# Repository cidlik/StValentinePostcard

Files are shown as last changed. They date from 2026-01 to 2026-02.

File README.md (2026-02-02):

# Идея

Сделать валентинку в виде печатной платы с микроконтроллером и светодиодами. Должна работать от
часовой батарейки. Основные пункты:

* должна быть дешевой;
* должно быть минимум компонентов (см. предыдущий пункт);
* должна быть низкопотребляющей;
* все компоненты, кроме светодиодов и кнопки, должны быть на обратной стороне платы.

Эскиз на рисунке ниже:

<figure style="text-align: center">
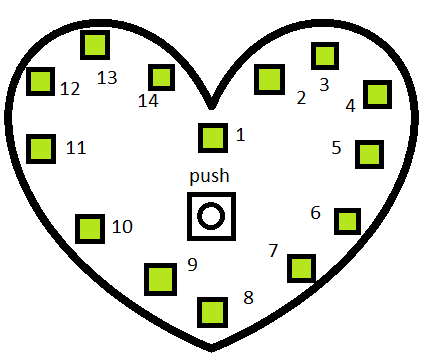
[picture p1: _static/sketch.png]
sketch
	
	<figcaption style="text-align: center">Эскиз устройства</figcaption>
</figure>

# Выбор светодиодов

Основные варианты:

* Обычные светодиоды, например, [TO-1608BC-MRE](https://www.chipdip.ru/product/to-1608bc-mre-svetodiod-krasnyy-smd-1608-112mkd-oasistek-9000414317):

    * (+) дешево
    * (+) энергоэффективно
    * (-) нужно много ног для управления
    * (-) сердито
    * Параметры:

        * Прямой ток 25 мА;
        * Прямое напряжение 2 В.

* Адресный, например, [SK(C)6812-RGBW-BW](https://www.chipdip.ru/product/sk-c-6812-rgbw-bw-neopixel-svetodiod-shenzhen-shiningled-9000373823):

    * (+) красиво, много режимов
    * (+) всего 2 провода для управления
    * (-) скорее всего будет больше жрать, хотя как запрограммировать
    * (-) борьба с наводками???
    * (-) дороже
    * Параметры:

        * Напряжение питания 3.7-5.5 В
        * Прямой ток 20-30 мА на один цвет.

# Оценка потребления

Выбираются 14 светодиодов TO-1608BC-MRE. Ток ограничивается до 15 мА через резистор. Режимы:

1. Один светодиод в единицу времени;
2. Все светодиоды разом (худший случай).

Для первого режима потребление по светодиодам 15 мА. Для второго - 15 * 14 = 210 мА.

Пусть будет _какая-то_ батарейка на 100 мАч (см. [таблицу](https://mosclock.ru/clock/o-garantii/zamena-batareek/tablitsa-sravneniya-chasovykh-batareek/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)). Тогда 

1. 100 / 15 ~= 6 ч на одни только светодиоды;
2. 100 / 210 ~= 0.5 ч на одни только светодиоды.

# Выбор микроконтроллера

Судя по всему, это будет STM32L0. Варианты:

1. [STM32L011F3P6](https://www.chipdip.ru/product/stm32l011f3p6-st-microelectronics-8003145100)
2. [STM32L010F4P6](https://www.chipdip.ru/product/stm32l010f4p6-mikrokontroller-arm-st-microelectronics-9001089803)

Почему STM:

* знаю, что там точно есть режимы с супер низким потреблением;
* знакомая платформа;
* не нужно будет докупать программатор, т.к. он есть.

Вариант 1:

* Корпус: TSSOP-20
* GPIO: 11-15 (зависит от того, что смогу сконфигурировать)
* Напряжение питания от 1.65 до 3.6 В.
* Тактирование от внутренней RC-цепочки.

Вариант 2 не рассматривается, т.к. 1-й вариант более чем устраивает.

# Что говорит ИИ?

* [Ответ 1](https://share.google/aimode/JZRhZsYDs94hqZSMV).
* [Ответ 2](https://share.google/aimode/ylKgjJaCaAhDsedJH).

# Выбор батарейки

Судя по всему, подходит [CR2032](https://www.dart.ru/cataloguenew/others/accumulator/html/cr2032.shtml).
Характеристики:

* выходное напряжение 3 В;
* выходной ток  0.4 мА;
* мощность 210 мА/ч.

# Блок-схема устройства

<figure style="text-align: center">
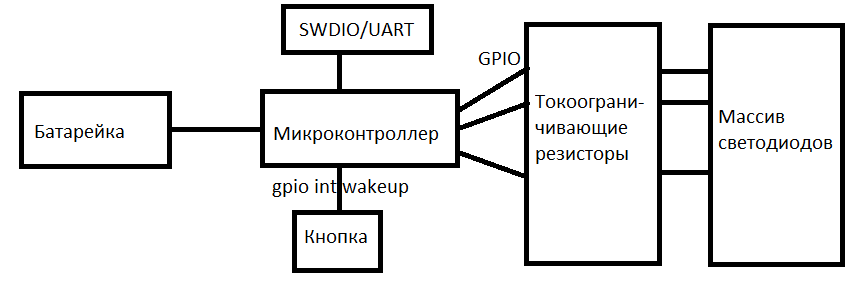
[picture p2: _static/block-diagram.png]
diagram
	
	<figcaption style="text-align: center">Блок-схема устройства</figcaption>
</figure>

# Попытка рассчитать буферный конденсатор

Потребляемая мощность:

$$ P = P_{mc} + P_d $$

где $P_{mc}$ - мощность, потребляемая МК, $P_d$ - мощность, рассеиваемая при зажигании одного
светодиода.

Требуется определить количество энергии, которое будет потреблено за 1 секунду. Оцениваем мощности:

* $ P_d = I^2 \cdot R = 0.015^2 \cdot 120 = 0.027 $ Вт;
* $ P_{mc} = 3 \cdot 0.0005 = 0.0015 $ Вт (грубая оценка, судя по всему не должно превышать этого значения, см.
"Table 22. Current consumption in Run mode, code with data processing running from Flash" для MSI
clock).

Тогда

$$ E = (0.027 + 0.0015) \cdot 1 = 0.0285\ Дж $$

Энергия конденсатора определяется выражением:

$$ E_c = {CU^2 \over 2} $$

Определяем разницу энергий - до включения светодиода и после выключения. Допустим, что напряжение
$U_{low}$ может упасть до 2 В. Эта разница - та энергия, которая уходит на микроконтроллер и на
горение светодиода. Тогда ёмкость:

$$ C = {2E \over U_0^2 - U_{low}^2} = {2 \cdot 0.0285 \over 3^2 - 2^2} = 0.0114\ Ф = 11400\ мкФ $$

Это при условии, что светодиод будет постоянно гореть, а микроконтроллер не будет переводиться в
низкопотребляющие режимы.

Пусть светодиод будет гореть 5% от всего времени, тогда $P_d = 0.027 \cdot 0.05 = 0.00135\ Вт$.
Тогда ёмкость:

$$ C = {2 \cdot (0.0015 + 0.00135) \over 3^2 - 2^2} = 1140\ мкФ$$

# Схема электрическая принципиальная

<figure style="text-align: center">
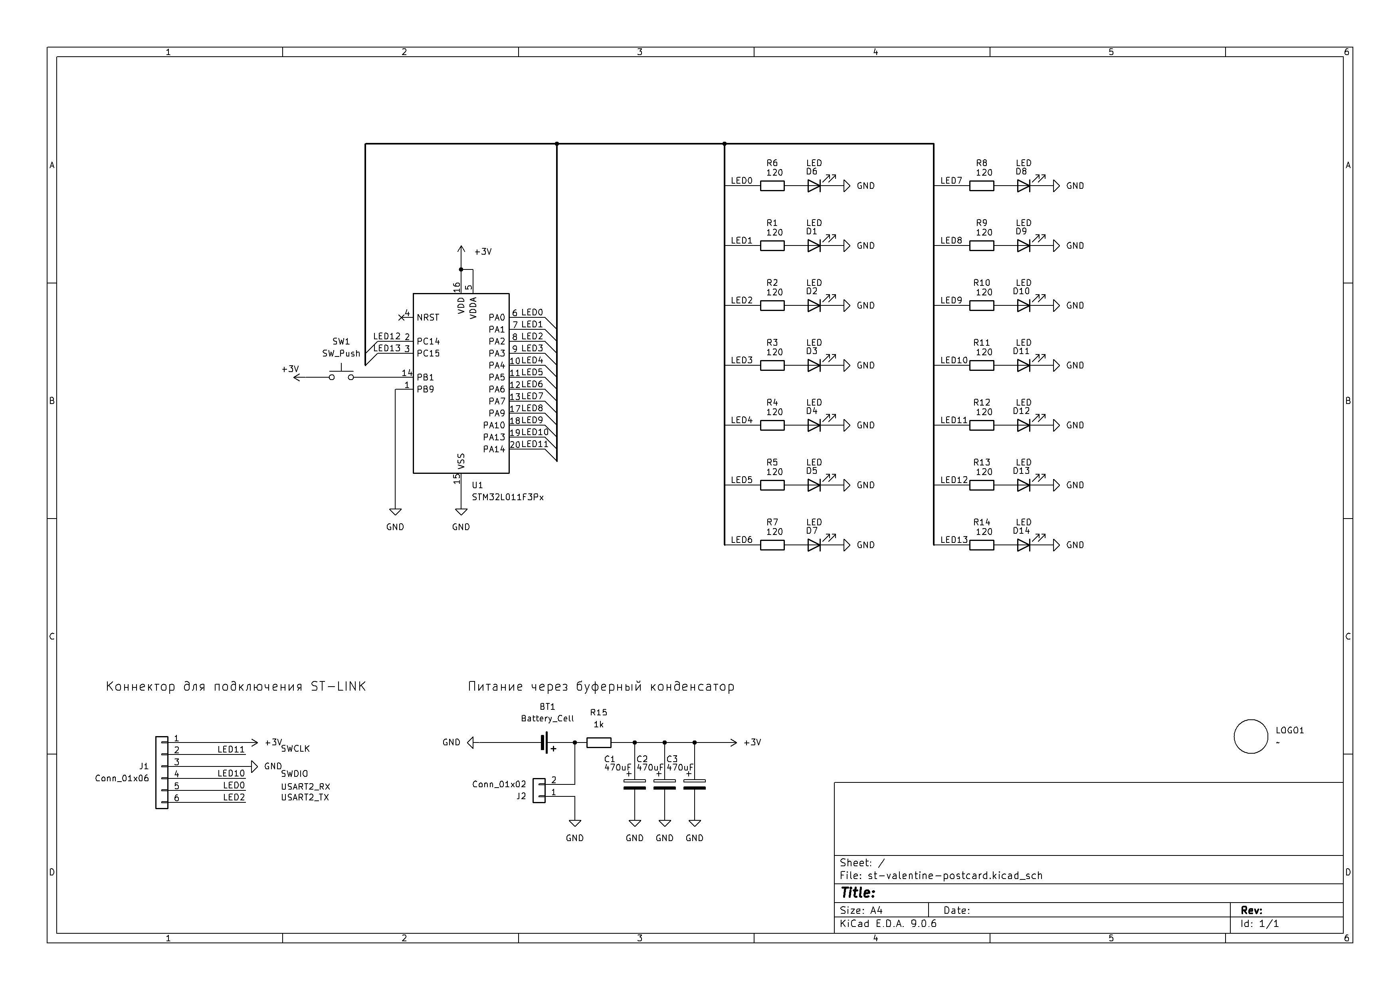
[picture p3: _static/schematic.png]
	
	<figcaption style="text-align: center">Схема электрическая принципиальная</figcaption>
</figure>

# Алгоритм сборки

* Пайка резисторов для светодиодов на нижней стороне платы: флюс, паста, установить резисторы,
  прогреть феном. После операции проверить мультиметром пайку (у каждого резистора есть переходное
  отверстие, использовать его и КП микроконтроллера).
  **Внимание!** R12 и R11 не запаивать!
* Пайка светодиодов на верхней стороне платы: флюс, паста, установить светодиоды, прогреть феном.
  После операции проверить мультиметром пайку (у каждого светодиода есть переходное отверстие,
  использовать его и землю).
* Пайка микроконтроллера: флюс, запаять паяльником краевые выводы. Затем движениями от МК до конца
  площадки нанести припой. После пайки проверить все линии. Проверить, нет ли КЗ по всем линиям.
* Запаять R15.
* Пайка кнопки. Кнопка размещается с верхней стороны. После установки в посадочное место обрезать
  выводы с другой стороны и запаять.
* Прошить МК прошивкой с флагом DEBUG, убедиться, что все ок.
* Прошить МК прошивкой без флага DEBUG.
* Запаять R12 и R11.
* Пайка конденсаторов (вывод с полосой - gnd). ~~Предположительно хватит 2-х конденсаторов~~
  Поставил все 3. Конденсаторы - с нижней стороны. После установки в посадочное   место обрезать
  выводы с другой стороны и запаять.
* Отчистить плату.
* Запаять отсек для батарейки и включить устройство.
* Зашкурить

# Итоговое потребление

* STATE_START: 380 мА (ничего не мигает)
* STATE_RUNNING_LED: 850 мА
* STATE_SYMMETRY_RUNNING_LED: 880 мА

Просадок напряжения питания осциллографом не увидел.

# Что можно улучшить?

## Конструктивно

* Вывести площадку с NRST, чтобы можно было не бояться закирпичить устройство.
* Добавить запаиваемую перемычку после R15, чтобы можно было более удобно измерять силу тока.
* Не забыть шелкографию при производстве плат))0))
* Выбрать какие-то другие светодиоды. Паять эти - сущий ад.

  * Возможно имеет смысл поставить низкопотребляющие светодиоды.

* Сделать площадки светодиодов и резисторов побольше чуть-чуть.
* Исправить посадочное место J1 - сейчас шаг маленький, не могу поставить стандартный PLS.
* Конденсатор после кнопки для фильтрации дребезга.
* Поставить запаиваемые перемычки на линиях LED10 и LED11, чтобы можно было паять сразу все резисторы. Тогда проблем с прошивкой быть не должно.

## Программно

* Улучшить реализацию фильтра дребезга.
* Добавить больше режимов.
* Поддержать Stop и Standby режимы.
* Более тонко понастраивать потребление через задержки.
* Использовать LSI вместо HSI16.

# Итоги

* Устройство заработало.

<figure style="text-align: center">
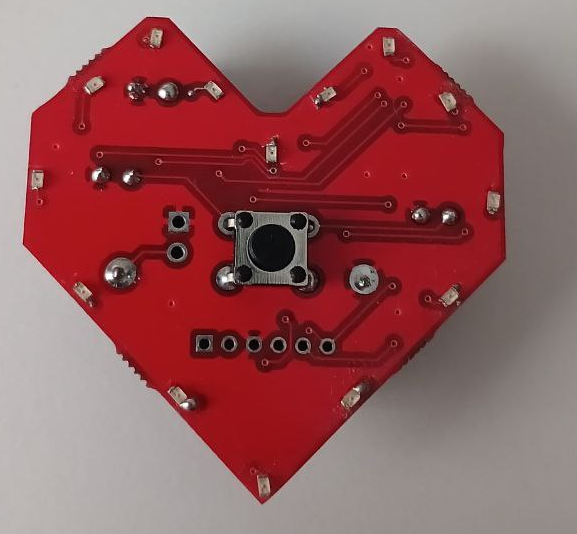
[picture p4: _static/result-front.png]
	
	<figcaption style="text-align: center">Результат. Передняя сторона</figcaption>
</figure>

<figure style="text-align: center">
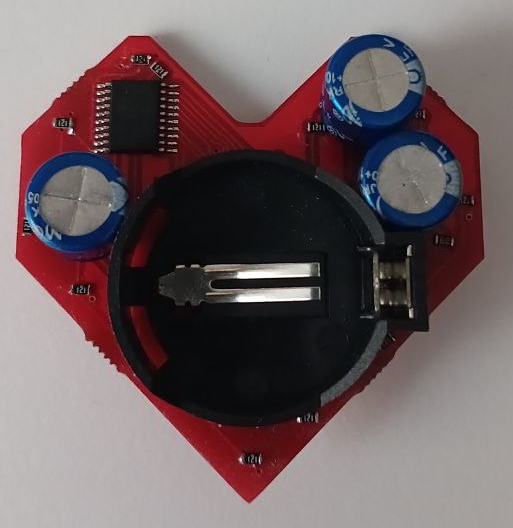
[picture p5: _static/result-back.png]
	
	<figcaption style="text-align: center">Результат. Задняя сторона</figcaption>
</figure>

<figure style="text-align: center">
	sketch
	<figcaption style="text-align: center">Результат в действии</figcaption>
</figure>

* Дешевым проект не назову - платы дорого вышли. Но делал срочный заказ, чтобы успеть к сроку, так
  что пойдет.

* Требование по низкому потреблению выдержано, можно улучшить.

# Для справки

* Светодиоды с низким током потребления:

    * [led smd 1ma](https://www.chipdip.ru/search?searchtext=led+smd+1ma)
    * [VLMA3100-GS08](https://www.chipdip.ru/product/vlma3100-gs08-led-yellow-smd-plcc-2-2-ma-2.2-v-594-vishay-8733971327)

# Полезные ссылки

* [Basics of power supply design for MCU](https://wiki.st.com/stm32mcu/wiki/Basics_of_power_supply_design_for_MCU)
* [Краткое руководство KiCad](https://docs.kicad.org/5.1/ru/getting_started_in_kicad/getting_started_in_kicad.html)
* [Ultra Low Power LED Flasher using the Padauk PFS154](https://cpldcpu.com/2021/02/07/ultra-low-power-led-flasher/)
* [Про буферные конденсаторы](https://habr.com/ru/articles/671232/)

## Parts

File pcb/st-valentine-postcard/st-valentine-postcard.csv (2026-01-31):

Reference | Qty | Value | DNP | Exclude from BOM | Exclude from Board | Footprint | Datasheet
BT1 | 1 | Battery_Cell |  |  |  | Battery:BatteryHolder_KLS5_CR2032_01 | https://www.chipdip.ru/product/kls5-cr2032-01-bh-642-ch224-2032-batareynyy-otsek-na-41183
C1,C2,C3 | 3 | 470uF |  |  |  | Capacitor_THT:C_Radial_D6.3mm_H7.0mm_P2.50mm | https://www.chipdip.ru/product/ecap-k50-35-mini-470mkf-6.3v-8x7mm-jb-capacitors-9000261777
D1,D2,D3,D4,D5,D6,D7,D8,D9,D10,D11,D12,D13,D14 | 14 | LED |  |  |  | Diode_SMD:D_0201_0603Metric | https://www.chipdip.ru/product/ltst-c190kskt-lite-on-electronics-8008844944
J1 | 1 | Conn_01x06 |  |  |  | Connector_PinHeader_2.00mm:PinHeader_1x06_P2.00mm_Vertical | ~
J2 | 1 | Conn_01x02 |  |  |  | Connector_PinHeader_2.54mm:PinHeader_1x02_P2.54mm_Vertical | ~
LOGO1 | 1 | ~ |  |  |  | Symbol:cdk_logo_6x6mm
R1,R2,R3,R4,R5,R6,R7,R8,R9,R10,R11,R12,R13,R14 | 14 | 120 |  |  |  | Resistor_SMD:R_0201_0603Metric_1.6x0.8 | https://www.chipdip.ru/product/0.1vt-0603-120-om-1-rc0603fr-07120rl-chip-rezistor-yageo-9000103458
R15 | 1 | 1k |  |  |  | Resistor_SMD:R_0201_0603Metric_1.6x0.8 | https://www.chipdip.ru/product/0.1vt-0603-1-kom-rc0603fr-071kl-chip-rezistor-smd-yageo-9000176519
SW1 | 1 | SW_Push |  |  |  | Button_Switch_THT:SW_PUSH_6mm_H4.3mm | ~
U1 | 1 | STM32L011F3Px |  |  |  | Package_SO:TSSOP-20_4.4x6.5mm_P0.65mm | https://www.st.com/resource/en/datasheet/stm32l011f3.pdf

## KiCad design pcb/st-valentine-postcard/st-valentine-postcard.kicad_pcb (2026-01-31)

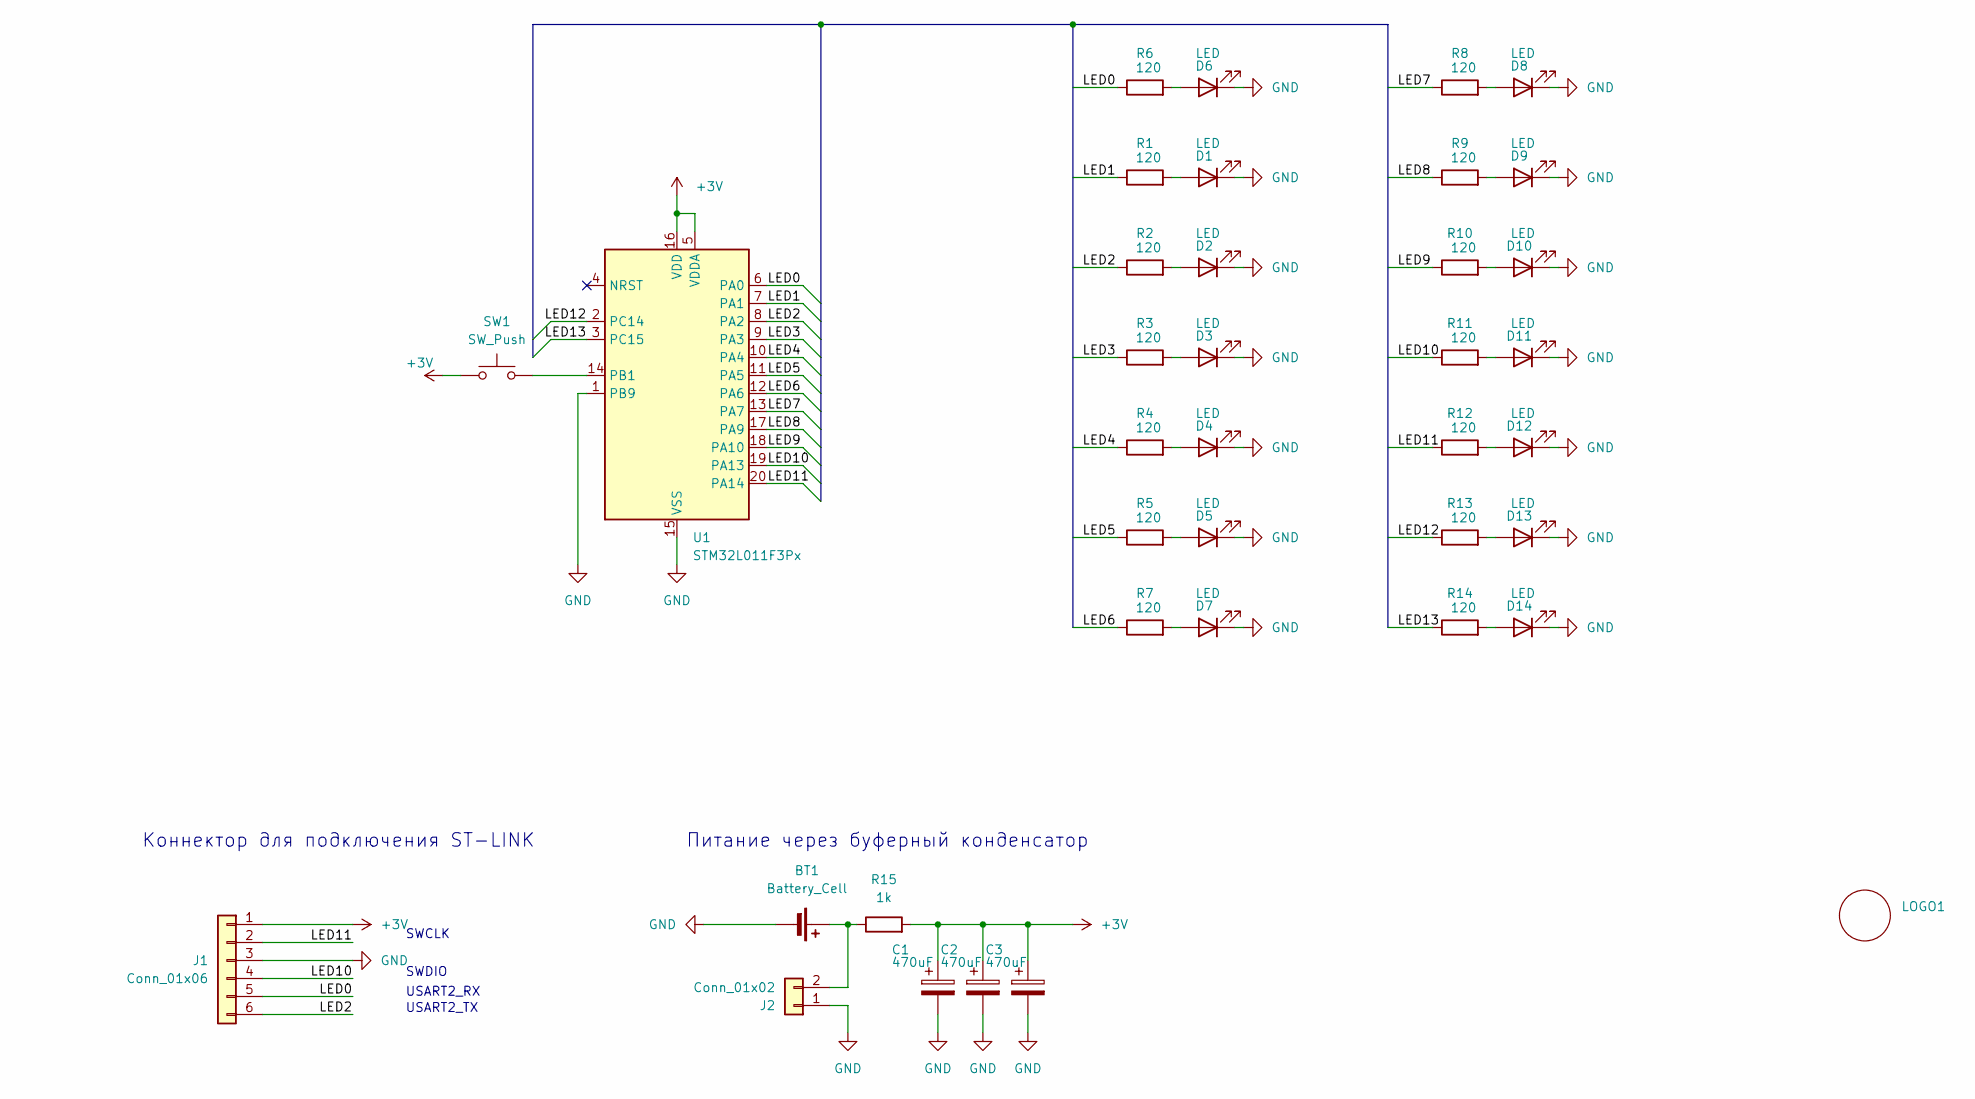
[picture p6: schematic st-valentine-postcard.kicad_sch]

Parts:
BT1: Battery_Cell; BatteryHolder_KLS5_CR2032_01
C1, C2, C3: 470uF; C_Radial_D6.3mm_H7.0mm_P2.50mm
D1, D2, D3, D4, D5, D6, D7, D8, D9, D10, D11, D12, D13, D14: LED; D_0201_0603Metric
J1: Conn_01x06; PinHeader_1x06_P2.00mm_Vertical
J2: Conn_01x02; PinHeader_1x02_P2.54mm_Vertical
LOGO1: cdk_logo_6x6mm
R1, R2, R3, R4, R5, R6, R7, R8, R9, R10, R11, R12, R13, R14: 120; R_0201_0603Metric_1.6x0.8
R15: 1k; R_0201_0603Metric_1.6x0.8
SW1: SW_Push; SW_PUSH_6mm_H4.3mm
U1: STM32L011F3Px; TSSOP-20_4.4x6.5mm_P0.65mm

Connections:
+3V: C1.1, C2.1, C3.1, J1.1, R15.2, SW1.1, U1.5 (VDDA), U1.16 (VDD)
/LED0: J1.5, R6.1, U1.6 (PA0)
/LED1: R1.1, U1.7 (PA1)
/LED2: J1.6, R2.1, U1.8 (PA2)
/LED3: R3.1, U1.9 (PA3)
/LED4: R4.1, U1.10 (PA4)
/LED5: R5.1, U1.11 (PA5)
/LED6: R7.1, U1.12 (PA6)
/LED7: R8.1, U1.13 (PA7)
/LED8: R9.1, U1.17 (PA9)
/LED9: R10.1, U1.18 (PA10)
/LED10: J1.4, R11.1, U1.19 (PA13)
/LED11: J1.2, R12.1, U1.20 (PA14)
/LED12: R13.1, U1.2 (PC14)
/LED13: R14.1, U1.3 (PC15)
GND: BT1.2 (-), C1.2, C2.2, C3.2, D1.1 (K), D2.1 (K), D3.1 (K), D4.1 (K), D5.1 (K), D6.1 (K), D7.1 (K), D8.1 (K), D9.1 (K), D10.1 (K), D11.1 (K), D12.1 (K), D13.1 (K), D14.1 (K), J1.3, J2.1, U1.1 (PB9), U1.15 (VSS)
unnamed: BT1.1 (+), J2.2, R15.1
unnamed: D1.2 (A), R1.2
unnamed: D2.2 (A), R2.2
unnamed: D3.2 (A), R3.2
unnamed: D4.2 (A), R4.2
unnamed: D5.2 (A), R5.2
unnamed: D6.2 (A), R6.2
unnamed: D7.2 (A), R7.2
unnamed: D8.2 (A), R8.2
unnamed: D9.2 (A), R9.2
unnamed: D10.2 (A), R10.2
unnamed: D11.2 (A), R11.2
unnamed: D12.2 (A), R12.2
unnamed: D13.2 (A), R13.2
unnamed: D14.2 (A), R14.2
unnamed: SW1.2, U1.14 (PB1)

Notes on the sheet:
USART2_TX
Коннектор для подключения ST-LINK
SWDIO
USART2_RX
SWCLK
Питание через буферный конденсатор

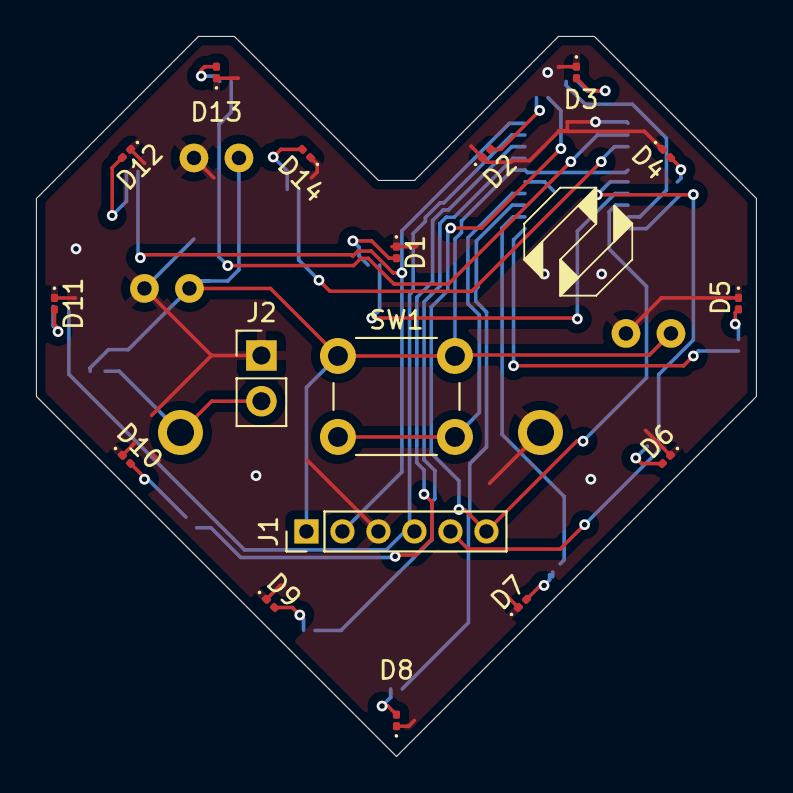
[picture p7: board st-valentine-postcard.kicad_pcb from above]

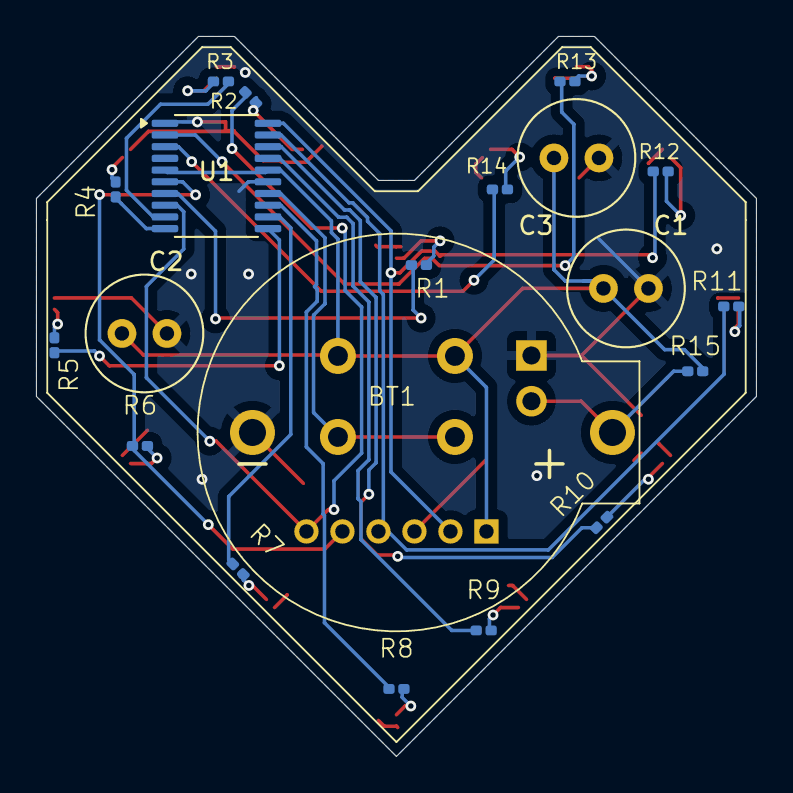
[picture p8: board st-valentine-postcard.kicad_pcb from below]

Board: 2 copper layers, 40.0 x 40.0 mm, 38 parts (20 on the bottom side), 32 nets.

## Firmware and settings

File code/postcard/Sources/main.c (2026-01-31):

#include <stdbool.h>
#include <stddef.h>
#include <stdint.h>

#include <stm32l0xx.h>

#ifndef DEBUG
#pragma message("This is release build")
#endif

#define USE_SLEEP_MODE

#define SLEEP_TIME_1S 	1000

#define BAD_LED			0xFFFFFFFF
#define MIN_LED			0
#define MAX_LED			13

#ifdef DEBUG
#define DEBUG_LED		1
#define SWCLK_LED		11
#define SWDIO_LED		10
#endif

#define BIT(x) (1 << (x))

#define poll(cond, attempts) ({ \
    int result = ERROR;            \
    for (int i = 0; i < (attempts); i++) { \
        if (cond) {             \
            result = SUCCESS;   \
            break;              \
        }                       \
    }                           \
    result;                     \
})

enum State {
	STATE_START,
	STATE_RUNNING_LED,
	STATE_SYMMETRY_RUNNING_LED,
#ifdef DEBUG
	STATE_DEBUG,
#endif
	STATE_LAST, // don't use it
};

static int state = STATE_START;
static bool is_lptim1_rdy = false;

/**
 * @brief Setup clocks to HSI16. HCLK has 1 MHz.
 */
int setup_clocks() {
	int ret = 0;

	RCC->CR = RCC_CR_HSIDIVEN | RCC_CR_HSION;
	ret = poll(RCC->CR & (RCC_CR_HSIRDY_Msk | RCC_CR_HSIDIVF_Msk), 10000);
	if (ret)
		return ret;

	RCC->CFGR = RCC_CFGR_STOPWUCK | RCC_CFGR_HPRE_DIV4 | RCC_CFGR_SW_HSI;
	ret = poll(RCC->CFGR & (RCC_CFGR_SWS_HSI), 10000);
	if (ret)
		return ret;

	RCC->IOPENR = RCC_IOPENR_GPIOAEN | RCC_IOPENR_GPIOBEN | RCC_IOPENR_GPIOCEN;
	RCC->APB1ENR = RCC_APB1ENR_LPTIM1EN;
	RCC->APB2ENR = RCC_APB2ENR_DBGEN | RCC_APB2ENR_SYSCFGEN;

	RCC->IOPSMENR = RCC_IOPSMENR_GPIOASMEN;
	RCC->APB1SMENR = RCC_APB1SMENR_LPTIM1SMEN;
	RCC->APB2SMENR = RCC_APB2SMENR_DBGSMEN | RCC_APB2SMENR_SYSCFGSMEN;

	// TODO: Probably I should use LSI for the LPTIM
	RCC->CCIPR |= RCC_CCIPR_LPTIM1SEL_1; // HSI16 clock

	return SUCCESS;
}

/**
 * Group of GPIO:
 * * PB1 - input, interrupt
 * * PA0-PA14 - output, GPIO except in the debug mode:
 *   * PA13 - SWDIO
 *   * PA14 - SWCLK
 * * PC14, PC15 - output, GPIO
 */
int setup_gpio() {
	uint32_t val = 0;

	/**
	 * GPIOA setup
	 */
	val = GPIO_MODER_MODE0_0 \
		  | GPIO_MODER_MODE1_0 \
		  | GPIO_MODER_MODE2_0 \
		  | GPIO_MODER_MODE3_0 \
		  | GPIO_MODER_MODE4_0 \
		  | GPIO_MODER_MODE5_0 \
		  | GPIO_MODER_MODE6_0 \
		  | GPIO_MODER_MODE7_0 \
		  | GPIO_MODER_MODE9_0 \
		  | GPIO_MODER_MODE10_0;
#ifdef DEBUG
	val |= GPIO_MODER_MODE13_1 | GPIO_MODER_MODE14_1;
#else
	val |= GPIO_MODER_MODE13_0 | GPIO_MODER_MODE14_0;
#endif
	GPIOA->MODER = val;

#ifdef DEBUG
	/**
	 * According to the "27.3.3 Internal pull-up & pull-down on SWD pins":
	 * * SWDIO: input pull-up (0b01)
	 * * SWCLK: input pull-down (0b10)
	 */
	GPIOA->PUPDR = GPIO_PUPDR_PUPD13_0 | GPIO_PUPDR_PUPD14_1;
	GPIOA->AFR[1] &= ~(GPIO_AFRH_AFSEL13 | GPIO_AFRH_AFSEL14);
#endif

	GPIOA->OTYPER = 0;  // push-pull
	GPIOA->OSPEEDR = 0; // low speed

	/**
	 * GPIOC setup
	 */
	GPIOC->MODER = GPIO_MODER_MODE14_0 | GPIO_MODER_MODE15_0;
	GPIOC->OTYPER = 0;  // push-pull
	GPIOC->OSPEEDR = 0; // low speed

	/**
	 * GPIOB setup
	 */
	GPIOB->MODER &= ~GPIO_MODER_MODE1;
	GPIOB->PUPDR = GPIO_PUPDR_PUPD1_1;
	GPIOB->OTYPER = 0;  // push-pull
	GPIOB->OSPEEDR = 0; // low speed

	return SUCCESS;
}

int setup_interrupt() {
	// LPTIM1 interrupt
	NVIC_EnableIRQ(LPTIM1_IRQn);
	NVIC_SetPriority(LPTIM1_IRQn, 1);

	// PB1 interrupt
	SYSCFG->EXTICR[0] = SYSCFG_EXTICR1_EXTI1_PB;
	EXTI->IMR = EXTI_IMR_IM1;
	EXTI->RTSR = EXTI_RTSR_RT1;
	EXTI->FTSR &= ~EXTI_FTSR_FT1;

	NVIC_EnableIRQ(EXTI0_1_IRQn);
	NVIC_SetPriority(EXTI0_1_IRQn, 0);

	return SUCCESS;
}

int setup_timer_lptim() {
	LPTIM1->IER = LPTIM_IER_CMPMIE;

	LPTIM1->CR &= ~LPTIM_CR_ENABLE;
	/**
	 * HSI16 is 16 MHz / 4 = 4 MHz
	 * 64 divider give us 62500 Hz for LPTIM. Because of the times is 16 bit
	 * we will can setup 1 second.
	 */
	LPTIM1->CFGR = LPTIM_CFGR_TIMOUT | (LPTIM_CFGR_PRESC_2 | LPTIM_CFGR_PRESC_1);
	LPTIM1->CR |= LPTIM_CR_ENABLE;

	return SUCCESS;
}

int start_timer_lptim(uint32_t ms) {
	if (ms > 1000)
		return ERROR;

	LPTIM1->CMP = (uint16_t)(ms * 62.5);
	LPTIM1->CR |= LPTIM_CR_SNGSTRT;

	return SUCCESS;
}

void delay(uint32_t val) {
	for (uint32_t i = 0; i < val; i++) {
		asm volatile ("nop");
	}
}

// TODO: Support Stop or Standby modes
void sleep_ms(uint32_t val) {
	start_timer_lptim(val);
	SCB->SCR &= ~SCB_SCR_SLEEPDEEP_Msk;
	asm volatile ("wfi");
	is_lptim1_rdy = false;
}

void LPTIM1_IRQHandler(void) {
	if (LPTIM1->ISR & LPTIM_ISR_CMPM_Msk) {
		LPTIM1->ICR |= LPTIM_ICR_CMPMCF;
		is_lptim1_rdy = true;
	}
}

void EXTI0_1_IRQHandler(void) {
	if (EXTI->PR & EXTI_PR_PIF1) {
		// Simple debounce filter
		NVIC_DisableIRQ(EXTI0_1_IRQn);
		delay(20000);
		NVIC_EnableIRQ(EXTI0_1_IRQn);

		EXTI->PR |= EXTI_PR_PIF1;
		state++;
		if (state == STATE_LAST) {
			state = STATE_START;
		}
	}
}

GPIO_TypeDef * get_gpio_from_led(uint8_t led) {
	if ((led >=0) && (led < 12))
		return GPIOA;
	else if ((led >= 12) && (led < 14))
		return GPIOC;
	else
		return NULL;
}

uint32_t get_pin_from_led(uint8_t led) {
	switch (led) {
		case 0:
		case 1:
		case 2:
		case 3:
		case 4:
		case 5:
		case 6:
		case 7:
			return led;
		case 8:
			return 9;
		case 9:
			return 10;
		case 10:
			return 13;
		case 11:
			return 14;
		case 12:
			return 14;
		case 13:
			return 15;
		default:
			return BAD_LED;
	}
}

int flash_led(uint8_t led) {
	GPIO_TypeDef *gpio = get_gpio_from_led(led);
	if (!gpio)
		return ERROR;
	uint32_t pin = get_pin_from_led(led);
	if (pin == BAD_LED)
		return ERROR;

	gpio->BSRR |= BIT(pin);			// BS - bit set
	sleep_ms(1);
	gpio->BSRR |= BIT(pin + 0x10);  // BR - bit reset
	sleep_ms(19);
	return SUCCESS;
}

int flash_two_leds(uint8_t led1, uint8_t led2) {
	GPIO_TypeDef *gpio1 = get_gpio_from_led(led1);
	if (!gpio1)
		return ERROR;
	GPIO_TypeDef *gpio2 = get_gpio_from_led(led2);
	if (!gpio2)
		return ERROR;

	uint32_t pin1 = get_pin_from_led(led1);
	if (pin1 == BAD_LED)
		return ERROR;
	uint32_t pin2 = get_pin_from_led(led2);
	if (pin2 == BAD_LED)
		return ERROR;

	gpio1->BSRR |= BIT(pin1);     		// BS - bit set
	sleep_ms(1);
	gpio1->BSRR |= BIT(pin1 + 0x10);  	// BR - bit reset
	sleep_ms(9);
	gpio2->BSRR |= BIT(pin2);			// BS - bit set
	sleep_ms(1);
	gpio2->BSRR |= BIT(pin2 + 0x10);  	// BR - bit reset
	sleep_ms(29);
	return SUCCESS;
}

void run_running_led_state() {
	for (int led = MIN_LED; led < MAX_LED + 1; led++) {
#ifdef DEBUG
		if ((led == SWCLK_LED) || (led == SWDIO_LED))
			continue;
#endif
		flash_led(led);
	}
}

void run_symmetry_running_led_state() {
	flash_led(1);
	flash_two_leds(2, 13);
	flash_two_leds(3, 12);
#ifndef DEBUG
	flash_two_leds(4, 11);
	flash_two_leds(5, 10);
#endif
	flash_two_leds(0, 9);
	flash_two_leds(6, 8);
	flash_led(7);
}

int main(void)
{
	int ret;

	ret = setup_clocks();
	if (ret)
		goto error_loop;

	ret = setup_timer_lptim();
	if (ret)
		goto error_loop;

	ret = setup_interrupt();
	if (ret)
		goto error_loop;

	/**
	 * Pins PA14 and PA13 are used as GPIO in release FW. But the pins
	 * are SWD pins also after reset. Without the delay we will not can
	 * update MC FW.
	 */
	sleep_ms(SLEEP_TIME_1S);
	ret = setup_gpio();
	if (ret)
		goto error_loop;

#ifdef DEBUG
	state = STATE_DEBUG;
#endif

	while (true) {
		switch (state) {
			case STATE_START:
				sleep_ms(SLEEP_TIME_1S);
				break;
			case STATE_RUNNING_LED:
				run_running_led_state();
				break;
			case STATE_SYMMETRY_RUNNING_LED:
				run_symmetry_running_led_state();
				break;
#ifdef DEBUG
			case STATE_DEBUG:
				flash_led(DEBUG_LED);
				break;
#endif
			default:
				goto error_loop;
		}
	}

error_loop:
	while (true) {
		delay(SLEEP_TIME_1S);
	}
}
